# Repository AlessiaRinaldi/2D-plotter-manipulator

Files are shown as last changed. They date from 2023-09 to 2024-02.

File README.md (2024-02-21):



<!-- LOGO -->
<br />
<div align = "center">
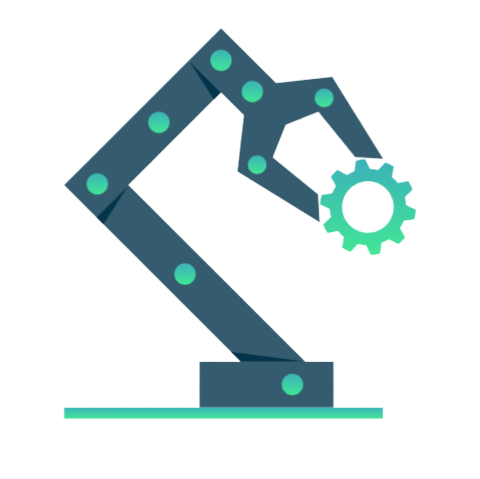
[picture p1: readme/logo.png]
    

<h3 align = "center">Embedded 2D SCARA-Model Pen Plotter</h3>

  <p align = "center">
    A Computer-Vision-based IoT robotic arm with pen plotting functionalities
    <br />
    <a href="https://drive.google.com/file/d/1LAqIMSbVnsYpsb-NP7bkUvp38VYiv7PE/view?usp=drive_link"><strong>Watch the demo »</strong></a>
    <br />
    <br />
    <h6>
    <a href="https://github.com/AlessiaRinaldi">Alessia Rinaldi</a>
    ·
    <a href="https://github.com/TianShi14">Angelo Nutu</a>
    ·
    <a href="https://github.com/alterlleo">Leonardo Pasquato</a>
    </h6>
  </p>
</div>

<!-- TABLE OF CONTENTS -->
- [Overview](#overview)
- [About The Project](#about-the-project)
  - [Structure](#structure)
  - [Telegram Bot](#telegram-bot)
  - [Communication and actuation](#communication-and-actuation)
- [Getting started](#getting-started)
  - [Raspberry setup](#raspberry-setup)
    - [UART communication setup](#uart-communication-setup)
    - [Telegram bot and vectorialization setup](#telegram-bot-and-vectorialization-setup)
  - [Hardware setup](#hardware-setup)
    - [Servo motors](#servo-motors)
  - [Raspberry and MSP432 wiring](#raspberry-and-msp432-wiring)
- [Files Organization](#files-organization)
- [Work Organization](#work-organization)
- [Roadmap](#roadmap)

<!-- Overview -->
## Overview

This project revolves around transforming digital images into computer-crafted printed drawings. 

In contrast to the conventional Cartesian structure commonly found in 3D printers, our apparatus is fashioned in the likeness of a human arm, introducing a distinctive approach to the process.

Users are prompted to effortlessly upload their desired images to our <a href = "https://web.telegram.org/k/#@pen_plotter_bot">Telegram bot</a>, which proceeds to carry out a vectorization process, resulting in a comprehensive `JSON` file containing vectors.
Following the image vectorization process, the `JSON` document will detail the exact positions determined to be followed by the manipulator. This document will be available in the Raspberry pi Zero memory and a serial communication between the `Raspberry` and the `MSP432` will enable the line-to-line interpretation of the file by the second one. Then the `MSP432` will compute the motor angles starting by the positions read and will actuate them to carry out the movement

<p align="right">(<a href="#top"> back to top </a>)</p>

<!-- ABOUT THE PROJECT -->
## About The Project

In the following sections, we'll break down the project's components.

### Structure

The structure of the 2D pen plotter comprises two links: one linking the first servo to the second, and the other connecting the second servo to the third. To establish clarity, we define the following reference frames:

- Frame 0: this represents the absolute frame, identical to the paper's frame.
- Frame 1: aligned with the first link, its x-axis parallels the link's axis, and its origin coincides with the servo 1 pin.
- Frame 2: similar to frame 1 but relative to the second link and motor. 

The outcome is a manipulator akin to a human arm, with its end-effector capable of drawing along points specified in the file aforementioned.

For visual clarification, refer to the accompanying image:

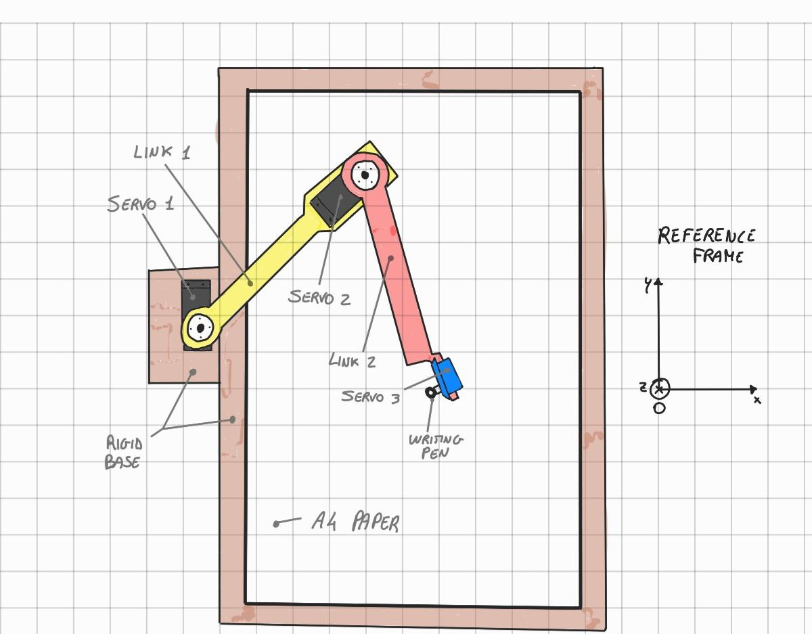
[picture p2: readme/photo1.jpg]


The third servo serves to raise and lower the attached pen:

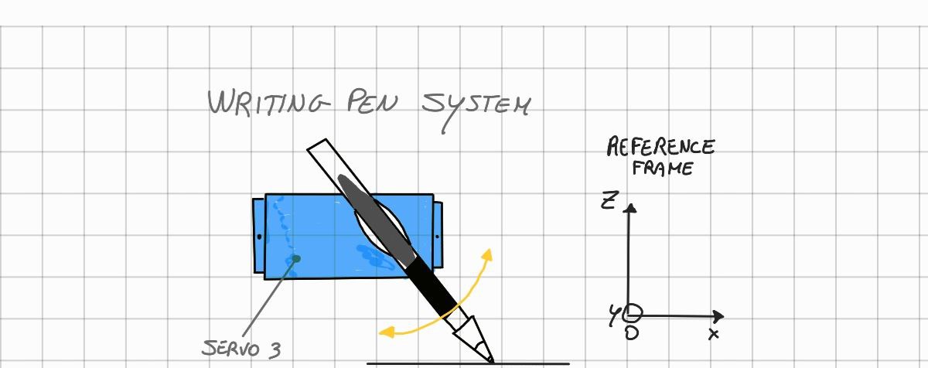
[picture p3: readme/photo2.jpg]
Frame2


### Telegram Bot

Our interface of choice for users looking to convert their chosen image into a drawing is a `Telegram bot`. Upon receiving the user's selected image, it initiates a structured sequence of Computer Vision algorithms. It systematically begins with a grayscale conversion, followed by Canny edge detection for precise boundary identification. Subsequently, a Gaussian blur is applied for image smoothing, and a Sobel operator to enhance edge definition.

These algorithms work alongside contouring techniques shaping distinct forms and structures within the image. Line sorting is then employed to organize the details. The outcome is a meticulously processed, vectorized image prepared for submission to the microcontroller. Throughout this process, the Telegram bot provides real-time updates on the processing status, and furthermore submits the vectorized image to the user for confirmation.

<br/>

### Communication and actuation

Following the image processing, the Telegram bot proceeds to save a `.json` file in a common folder included in the Raspberry Pi memory, encapsulating the vectors that constitute the image. The file is then parsed by another `Python` script, which extracts vector points. Those are then individually communicated to the MSP432.

The aforementioned communication between the two boards works via UART protocol, and upon receiving these points the MSP432 coordinates the movement of the servomotors to the specified position.

## Getting started

This project is designed for execution on the MSP432 embedded platform, utilizing `Texas Instruments' DriverLib` to operate at a higher abstraction level. While the MSP432 can be programmed using Code Composer Studio, this project has been configured to leverage Visual Studio Code with the `PlatformIO extension` due to more familiarity with the tool.

PlatformIO is an open-source extension for Visual Studio Code, providing compatibility with a wide range of embedded systems. Although commonly used for Arduino development without its native IDE, it also supports the coding of STM32 and MSP boards.

To facilitate the integration of the DriverLib into the project, it is included in the _lib_ folder. Within this folder, sub-folders exist for each pair of header and definition files (.h and .c). Consequently, every #include statement for the DriverLib has been modified to exclude the path of the sub-libraries, as they are all housed in the same folder.

To use this project, install PlatformIO on your Visual Studio Code, clone this repository, and open the project from PlatformIO. All the necessary components for the MSP432 board are consolidated here.

An additional element of the project involves the Raspberry Pi 0 W for Human Machine Interaction (HMI). The setup requires the necessary connections for serial communcation between the MSP432 and Raspberry Pi, while it's only required to execute the primary Python script _plotter_bot.py_ to initialize and engage with the Telegram Bot.

### Raspberry setup

Testing of the platform has been conducted on `Raspbian version 11.0` and later, as well as Ubuntu 22.02 and above. The prerequisites for the runtime environment include a minimum `Python 3.10 version`, and all additional Python package dependencies.

Before installing dependencies, ensure that the `pip` command is installed using the following:

``` bash
sudo apt install pip 
```
On the _Raspberry Pi 0_ there might be insufficient memory space in the directory `/var/cache/apt/archives`. It's possible to solve this issue: expand the filesystem to SD Card (it's recommended to use at least an SD card with at least 8Gb) by doing `sudo raspi-config` ⟶ `Advanced` ⟶ `Expand Filesystem`.

The same is also achievable through the command line by executing:

``` bash
sudo raspi-config --expand-rootfs
```    

#### UART communication setup

For initiating serial communication, it's necessary to install the `pyserial` module using the command:

``` bash
pip install pyserial
```

In this project, the `/dev/serial0` port is utilized. Before the first run, enable it by editing the file `/boot/config.txt`

``` bash
sudo nano /boot/config.txt
```
and append the following line:

```
enable_uart=1
```

#### Telegram bot and vectorialization setup

Additionally, for booting and usage of the Telegram Bot, several additional modules are needed. 

Tu run the bot, install `python-telegram-bot`, as well as `cairo-svg` for SVG conversion (to display the vectorized image to the user) and `numpy` for serial decoding of the image sent by the user. Execute the following command:
```
pip install python-telegram-bot cairosvg numpy
```
For the backend image-related processes, the required modules include the headless version of `opencv` for the various processing algorithms and `PIL` for image handling. Install them with the following:

``` bash
pip install opencv-python-headless Pillow
```

<br/>

Reboot the system, and everything should be set up and ready for execution.

### Hardware setup

#### Servo motors

The required motors are 3 and are connected to the MSP432 as this:
| Servo reference name | Servo type | MSP432 pin|
| --- | --- | --- |
| shoulder | MG996R | 2.4 |
| elbow | MG996R | 5.6 |
| pen lifter | SG90 | 2.5 |

The pull-up circuit is required for the *shoulder* and *elbow* servos, the third is a smaller one and it allows a 3.3V PWM signal.

### Raspberry and MSP432 wiring
The UART connection between MSP432 and Raspberry pi 0 requires only one wire, since in this case the transmission is mono-directional. The transmitter must be the Raspberry and the receiver the MSP432 accordingly to the following connections:

| Raspberry | MSP432 |
| --- | --- |
| TX = 14 | RX = 3.2 |

Where the pinout schematic of the raspberry is:

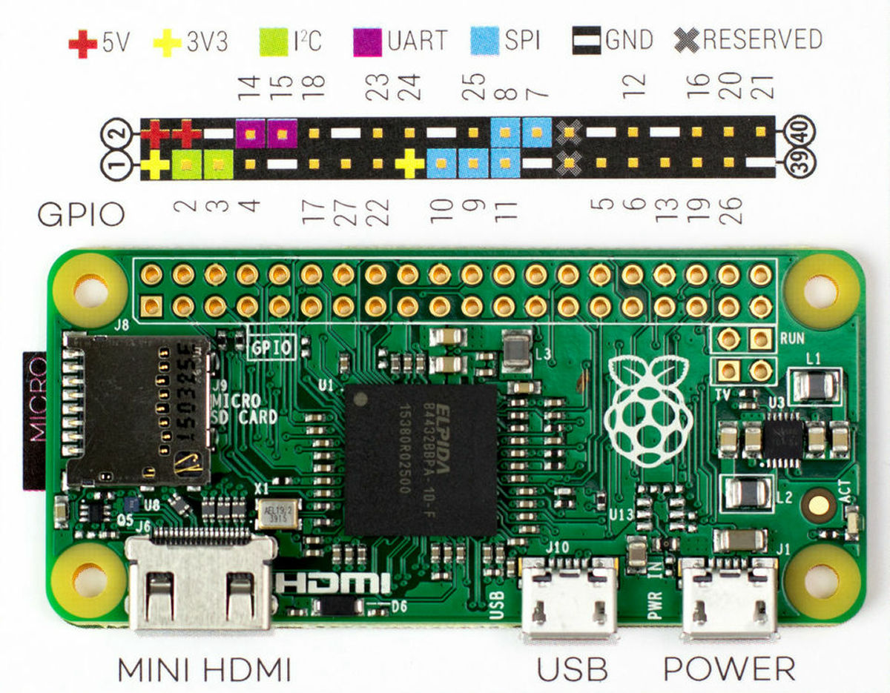
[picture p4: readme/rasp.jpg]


## Finished project

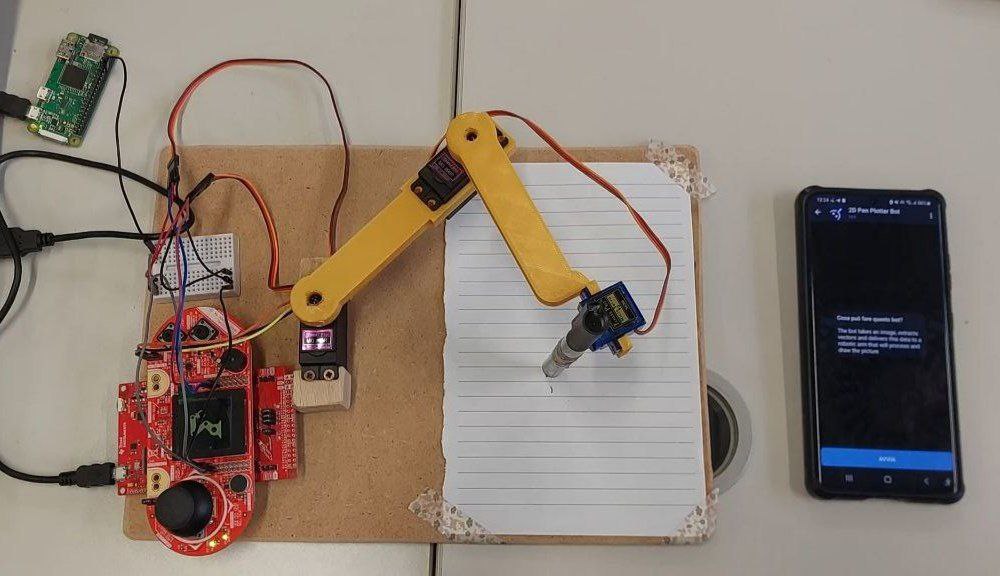
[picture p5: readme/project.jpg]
Project


## Files Organization
```
.
├── 3D-structure
├── MSP-codes
|   ├── include
|   ├── lib
|   |   ├── driverlib
|   |   ├── Crystalfontz128x128_ST7735
|   |   └── HAL_MSP_EXP432P401R_Crystalfontz128x128_ST7735
|   └── src
|       ├── pictures
|       |   ├── Default.c
|       |   ├── DrawingBar.c
|       |   └── images.h
|       ├── main.c
|       ├── motors.h
|       ├── motors.c
|       ├── communication.h
|       ├── communication.c
|       ├── screen.h
|       ├── screen.c
|       ├── inithw.h
|       └── inithw.c
├── rasp-communication
|   └── communication_rasp.py
├── Vectorization-bot
|   ├── images
|   ├── linedraw.py
|   └── plotter_bot.py
└── README.md

```

<!-- Working Organization -->
## Work Organization

The entire group began discussions on the project's core concept starting from the outset of the course, eventually settling on the designing and manfacturing of the 2D pen plotter. Over the subsequent weeks, individual work was precluded, and all decisions related to the project were made collectively. Consequently, tasks were distributed among team members as follows:

- Angelo Nutu assumed responsibility for image processing, setting up the Telegram bot and feedback screen;
- Alessia Rinaldi took charge of serial communication between the Raspberry Pi and the MSP432;
- Leonardo Pasquato was tasked with designing the 3D structure and managing motor control actuation for the MSP432;

<p align="right">( <a href="#top">back to top</a> )</p>

<!-- ROADMAP -->
## Roadmap

- [X] Telegram Bot
- [X] Point-to-Point connection
    - [X] Protocol implementation
    - [X] Transmission 
- [X] Motor control
    - [X] Math implementation
    - [X] Motor PWM definition
- [X] Feedback screen

<p align="right">( <a href="#top">back to top</a> )</p>

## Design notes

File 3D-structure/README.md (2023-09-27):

## 3D printer specs
|piece|fill density|precision|time|
|---|---|---|---|
support 0 |   20%   |  0.2 mm | |
link 1    |   10%   |  0.2 mm | |
link 2    |   10%   |  0.2 mm | |

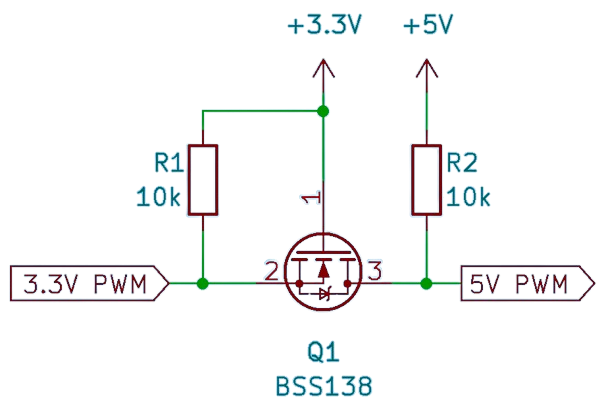
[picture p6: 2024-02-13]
readme/pullup2.png

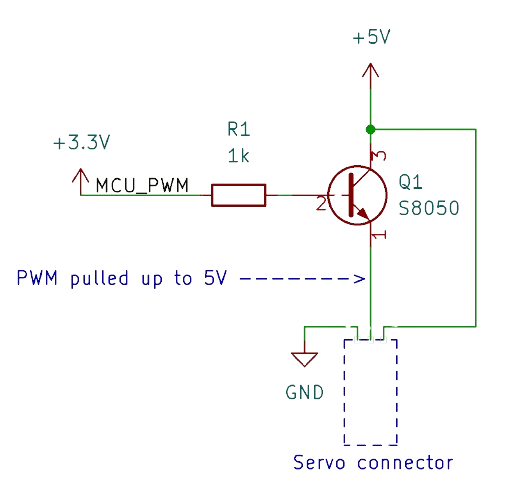
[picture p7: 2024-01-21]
readme/pullup.png

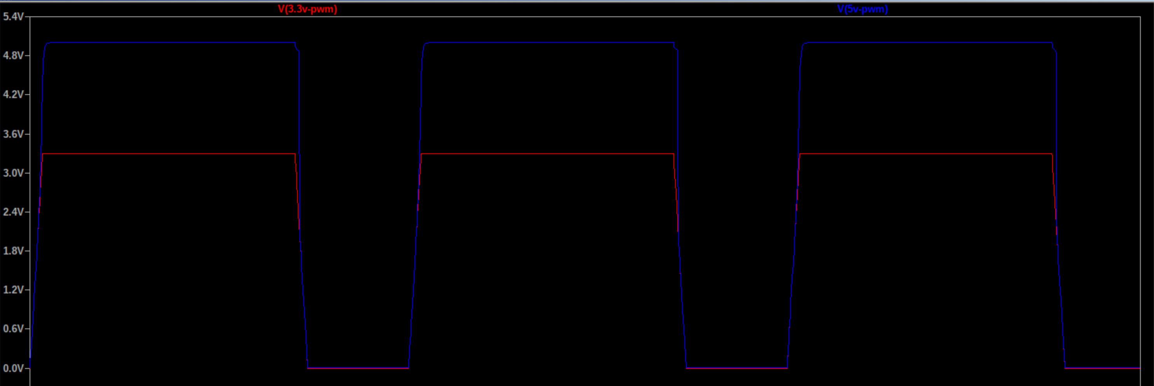
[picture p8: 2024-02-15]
readme/screensim.png

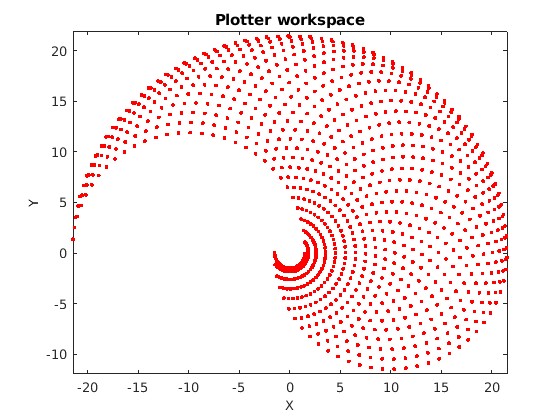
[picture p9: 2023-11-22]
3D-structure/workspace.jpg

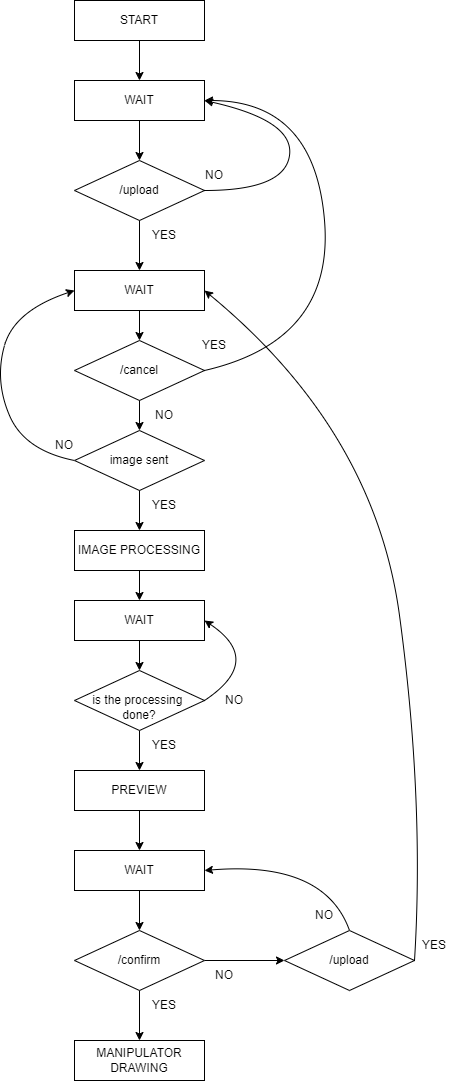
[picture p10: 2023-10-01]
readme/msf.png

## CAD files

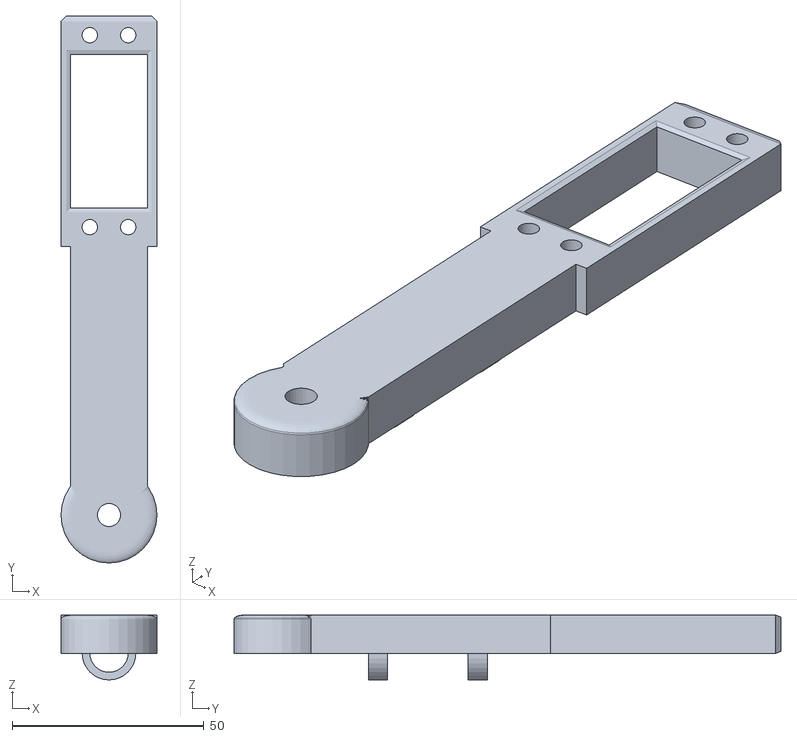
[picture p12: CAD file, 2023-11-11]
3D-structure/STL/link1def.stl
25.0 x 142.5 x 16.9

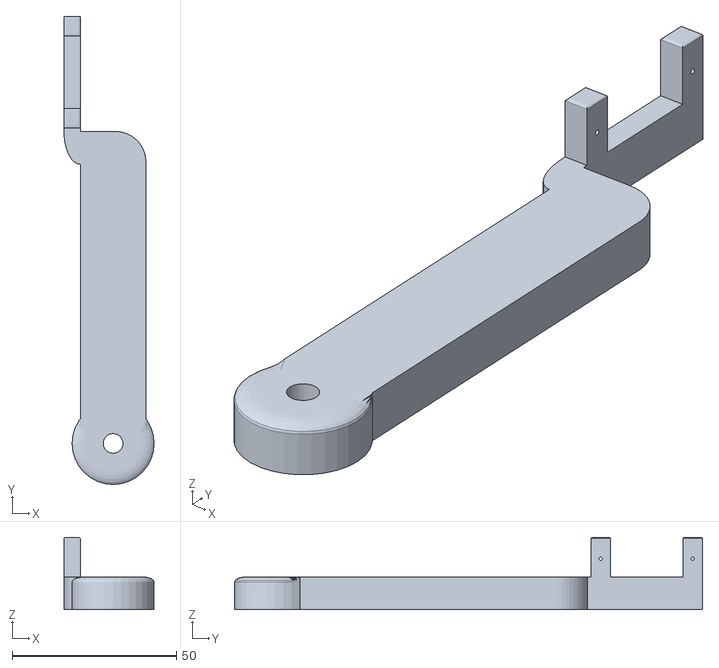
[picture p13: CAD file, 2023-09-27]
3D-structure/STL/link2def.stl
27.5 x 142.5 x 22.0

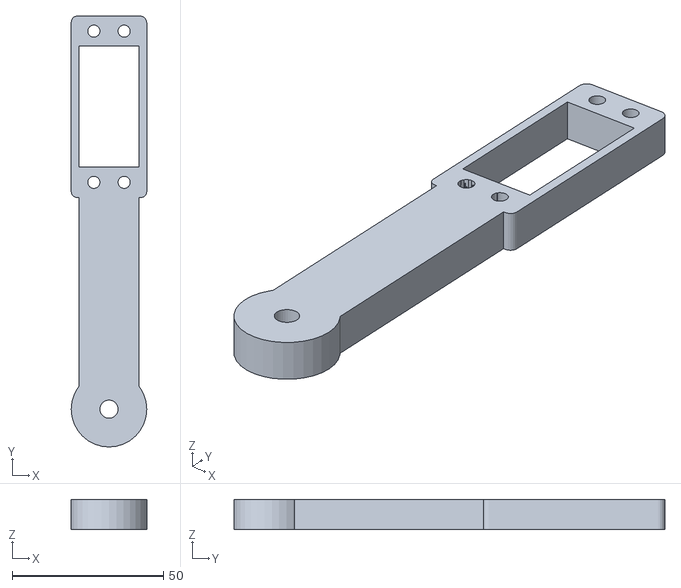
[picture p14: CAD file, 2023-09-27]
3D-structure/STL/link1demo.stl
25.0 x 142.5 x 10.00

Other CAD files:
3D-structure/Blender-source/link1def.blend
3D-structure/Blender-source/link2.blend
3D-structure/Blender-source/link2def.blend
3D-structure/Blender-source/supp-frame0.blend

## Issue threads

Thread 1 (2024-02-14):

TODO

alterlleo, 2024-02-14:
- [ ] test pwm pull up
- [ ] check if the blue servo needs 5V pwm
- [ ] hierarchy between telegram bot and uart script

Closed 2024-02-22.

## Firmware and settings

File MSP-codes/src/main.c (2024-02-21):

#include "msp.h"
#include "motors.h"
#include <driverlib.h>
#include "stdio.h"
#include "math.h"
#include <stdint.h>
#include <stdbool.h>
#include "inithw.h"

pos_t current_position;

int main(void){
    inithw();

    for(int i = 0; i < 5000; i++){
        // starting delay
    }

    while(1){
        Interrupt_enableSleepOnIsrExit();
        PCM_gotoLPM0InterruptSafe();
        
    }
}

void EUSCIA2_IRQHandler(void){
    uint32_t status = UART_getEnabledInterruptStatus(EUSCI_A2_BASE);
    
    if(status & EUSCI_A_UART_RECEIVE_INTERRUPT_FLAG){
        if (get_vector){
            UART_get_vectors();
        } else {
            UART_get_data(&current_position);
        }        
    }
}

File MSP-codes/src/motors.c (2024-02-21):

#include "motors.h"
#include "stdio.h"
#include "math.h"

/*

PWM SETUP:
the pwm pin 2.6 is connected to the third servo, the one that lift and put down the pen;
the pwm pin 2.4 is connected to the second servo, the elbow;
the pwm pin 5.6 is connected to the first servo, the fixed shoulder

Set pwmconfig structs

*/

Timer_A_PWMConfig pwm_config_shoulder =
{
        TIMER_A_CLOCKSOURCE_SMCLK,
        TIMER_A_CLOCKSOURCE_DIVIDER_48,
        1280,
        TIMER_A_CAPTURECOMPARE_REGISTER_1,
        TIMER_A_OUTPUTMODE_RESET_SET,
        48 
};

Timer_A_PWMConfig pwm_config_elbow =
{
        TIMER_A_CLOCKSOURCE_SMCLK,
        TIMER_A_CLOCKSOURCE_DIVIDER_48,
        1280,
        TIMER_A_CAPTURECOMPARE_REGISTER_1,
        TIMER_A_OUTPUTMODE_RESET_SET,
        48
};

Timer_A_PWMConfig pwm_config_pen =
{
        TIMER_A_CLOCKSOURCE_SMCLK,
        TIMER_A_CLOCKSOURCE_DIVIDER_48,
        1280,
        TIMER_A_CAPTURECOMPARE_REGISTER_2,              // CCR2 for 2.5 pin pwm, 2.6 is occupied by the screen
        TIMER_A_OUTPUTMODE_RESET_SET,
        64
};
/*
Useful current position counter of the arm and the pen
*/
pos_t current_position;
bool past_pen_position;

uint16_t current_duty_shoulder = 0;
uint16_t current_duty_elbow = 0;


void init_servo(void){
    // configure 2.4 pin as shoulder pwm
    MAP_GPIO_setAsPeripheralModuleFunctionOutputPin(GPIO_PORT_P2, GPIO_PIN4,GPIO_PRIMARY_MODULE_FUNCTION);

    // configure 5.6 pin as elbow pwm
    MAP_GPIO_setAsPeripheralModuleFunctionOutputPin(GPIO_PORT_P5, GPIO_PIN6,GPIO_PRIMARY_MODULE_FUNCTION);

    // configure 2.5 pin as pen lifter pwm
    MAP_GPIO_setAsPeripheralModuleFunctionInputPin(GPIO_PORT_P2, GPIO_PIN5, GPIO_PRIMARY_MODULE_FUNCTION);

    MAP_Timer_A_generatePWM(TIMER_A0_BASE, &pwm_config_shoulder);
    MAP_Timer_A_generatePWM(TIMER_A2_BASE, &pwm_config_elbow);
    MAP_Timer_A_generatePWM(TIMER_A0_BASE, &pwm_config_pen);

}

void set_pen(){

    if(past_pen_position != current_position.pen){

        // update past pen position
        past_pen_position = current_position.pen;

        if(current_position.pen == true){
            // the pen must be down
            pwm_config_pen.dutyCycle = 4;
            MAP_Timer_A_generatePWM(TIMER_A0_BASE, &pwm_config_pen);

        } else{
            // the pen must be high
            pwm_config_pen.dutyCycle = 64;
            MAP_Timer_A_generatePWM(TIMER_A0_BASE, &pwm_config_pen);

        }
    }
}


void set_servo(uint16_t duty1, uint16_t duty2){

    set_pen();

    /*
    Check duty cycle plausibility
    */   
    if(duty1 >= SERVO_DUTY_CYCLE_MIN && duty1 <= SERVO_DUTY_CYCLE_MAX && duty2 >= SERVO_DUTY_CYCLE_MIN && duty2 <= SERVO_DUTY_CYCLE_MAX){

        // set shoulder
        pwm_config_shoulder.dutyCycle = duty1;
        pwm_config_elbow.dutyCycle = duty2;
        
        current_duty_shoulder = pwm_config_shoulder.dutyCycle;
        MAP_Timer_A_generatePWM(TIMER_A0_BASE, &pwm_config_shoulder);

        current_duty_elbow = pwm_config_elbow.dutyCycle;
        MAP_Timer_A_generatePWM(TIMER_A2_BASE, &pwm_config_elbow);      
    } 
}

uint16_t angle_2_duty(float angle){
    // conversion from radians to duty cycle    
    // pi : (SERVO_DUTY_CYCLE_MAX - SERVO_DUTY_CYCLE_MIN) = angle = x

    uint16_t duty = ((angle * (SERVO_DUTY_CYCLE_MAX - SERVO_DUTY_CYCLE_MIN)) / 3.1415) + SERVO_DUTY_CYCLE_MIN;
    return duty;
}


void set_position(pos_t *pos){

    /*
    Obtain angles from 2D points
    */

    current_position = *pos;             //check this, maybe it's not the right place

    uint8_t x = pos -> x;
    uint8_t y = pos -> y;

    float hypotenuse = sqrt(pow(x, 2) + pow(y, 2));
    float hypotenuse_angle = asin(x / hypotenuse);

    float inner_angle = acos((pow(hypotenuse, 2) + pow(LINK_1, 2) - pow(LINK_2, 2)) / (2 * hypotenuse * LINK_1));            // the acos return the angle in radians
    float outer_angle = acos((pow(LINK_1, 2) + pow(LINK_2, 2) - pow(hypotenuse, 2)) / (2 * LINK_1 * LINK_2));

    float servo_1_angle = hypotenuse_angle - inner_angle + 1.57/2;
    float servo_2_angle = 3.14 - outer_angle - 1.57;

    /*
    Check on workspace, better than this
    */
    if(hypotenuse < (LINK_1 + LINK_2)){
 
        // set servo
        uint16_t duty1 = angle_2_duty(servo_1_angle);
        uint16_t duty2 = angle_2_duty(servo_2_angle);
        set_servo(duty1, duty2);
    }
}

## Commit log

2023-09-27 3D: link1 and support0 done
    [link1def.blend, link1demo.stl, link2.blend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]
2023-09-27 3D: done link2
    [link1def.blend, link2.blend, link2def.blend]
2023-09-27 readme: update
    [link2def.stl]
2023-10-31 motors: first test draft
2023-10-31 motors: first test code, TODO: try it
2023-11-05 motors: wrong way, check dc manipulation
    [main.c, motors.c]
2023-11-06 motors: redo pwm with timer A0
2023-11-06 motors: acutation works
2023-11-06 motor: servo duty cycle calibration
2023-11-06 motors:check interrupt handler waiting
2023-11-07 motor: add mathematic, TODO: add second servo
2023-11-08 motor: add working test
2023-11-09 test: add second timer/motor
2023-11-11 3d: add stl
    [link1def.stl]
2023-11-13 motor: proper functions structure
2023-11-20 motor: generate_pwm works bad
2023-11-20 motor: change approach to upconfig
2023-11-22 motor: update set servo positions
2023-11-22 motor: first draft full functions
2023-11-22 screen: basic header files and function prototype
2023-11-28 ale fix photo path from leo pc
    [communication_rasp.py]
2023-11-28 communication: UART_init()
2023-11-29 motor: change angle type -> float
2023-12-13 motor/inithw: add more info
2023-12-18 motor: fix elbow motor duty
    [motors.c]
2024-01-17 motor: change to uin8_t
2024-01-17 communication/motors: first test does not work
    [communication.c, main.c, motors.c]
2024-01-17 motors: fix error
2024-01-18 communication: msp code fixed
    [communication.c, main.c]
2024-01-18 communication: 0 value fixed
    [communication_rasp.py]
2024-01-19 readme: add circuitry
2024-01-21 communication: main and rasp fixed
    [communication.c, communication_rasp.py, main.c]
2024-01-24 readme: update wiring
2024-02-12 pwm: add simulation
2024-02-13 pwm: update readme
2024-02-16 pwm pull doesn't work
    [motors.c]
2024-02-17 motors: review clock divider
2024-02-18 communication: UART works
2024-02-18 motors: update with timer_A_pwmconfig struct
2024-02-18 inithw: update for motors
2024-02-19 motors: works
2024-02-20 motors: servo pen candidate
2024-02-21 readme: update servo requirements
